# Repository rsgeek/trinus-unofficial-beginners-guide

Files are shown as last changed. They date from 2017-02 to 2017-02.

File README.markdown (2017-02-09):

# Trinus - The Unofficial Beginners Guide

This will enable Trinus owners that would like to contribute to the guide a better option via [Github Pull Requests](https://gist.github.com/Chaser324/ce0505fbed06b947d962).

You can also view the guide online using the Github Pages feature:

<https://drofnas.github.io/trinus-unofficial-beginners-guide/>

The latest compiled **PDF** document can be found in the [download](https://github.com/drofnas/trinus-unofficial-beginners-guide/tree/master/download) folder.

## Style Guide

This will go over the various styles/layout that are used throughout the Guide so that all contributions stay with the same format and it keeps a uniform look and feel.

### Text / Layout

For now, until this section of the style guide is flushed out, just copy the same style as the rest of the guide. It should cover the majority of things needed. Here's a [Markdown Cheatsheet](https://github.com/adam-p/markdown-here/wiki/Markdown-Cheatsheet) to help with any syntax not already used in the guide.

### Images

The original images (`orig` folder) are 3000px x 1500px (2:1) size. Then the images that are used in the document are just a reduction in size to 800px x 400px. If you want to have shorter height to your image, then you can create with a 4:1 ratio (3000px x 750px -> 800px x 200px).

Original Images (**PNG / JPG / PSD**):

* 3000px x 1500px (2:1)
* 3000px x 750px (4:1)

HTML / PDF Images (**PNG / JPG**):

* 800px x 400px (2:1)
* 800px x 200px (4:1)

#### Optimize Images

First thing you need to do is create the redued sized images (800 width) so that they can be optimized. All images should be uploaded to [TinyPNG.org](https://tinypng.com/) for processing. This process will reduce the file size of each image by as much as 70%. 

* Drag and drop images on to the website.
* Download the optimized version.
* Overwrite the images that you created for use for the HTML/PDF files (800w).

## Compiling

The HTML file is compiled using Pandoc (http://pandoc.org/index.html), see their website on how to install it on your machine. This will enable you to compile the latest development branch of this guide.

### Generate HTML
Make sure to get Pandoc (http://pandoc.org/index.html) installed first so that you can run the following command. The exact command may vary depending on your OS; this was what was run in OSX. See their website for OS specific changes to the command:

    pandoc *.md > docs/index.html --css helpers/style.css

### Generate PDF

* First generate the HTML using Pandoc above.
* Open the HTML file in Chrome.
* Click on File -> Print
* Change your Destination (or Printer) to "Save as PDF"
* Click the Save button to save it locally.

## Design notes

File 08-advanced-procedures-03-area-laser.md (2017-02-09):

### Maximize Build Area - Laser Engraving 
Paul Drinkut helped troubleshoot ([Facebook Post](https://www.facebook.com/groups/Trinus3D/permalink/1315472305181210/?hc_location=ufi)) the reason why the Laser Engraver wasn’t using the full build area, this was due to the fact the Laser Mount didn’t have the same left offset that the Extruder Assembly had. 

So in order to fix this, a modification was made to the official 3D Model (original model can be found in the [Downloads](#download-it) section) to add in a small left offset of 5mm. This combined with the X/Y-Axis offset screws allowed for the maximum engraving area to be achieved. 

If you haven’t already, you will need to follow the process to [Maximizing Build Volume in 3D Printing](#maximize-build-volume---3d-printing) first, then you can print the fixed Laser Mount (below) to maximize your laser engraving area.

**Modified Laser Mount** <br/>
[https://github.com/.../files/trinus-offset_laser_holder.stl 
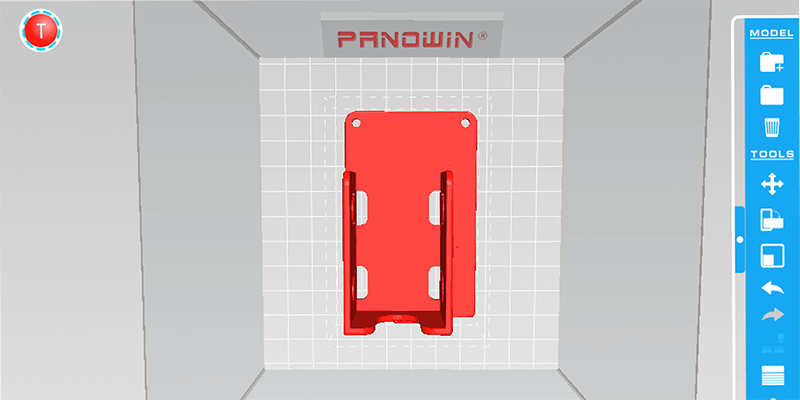
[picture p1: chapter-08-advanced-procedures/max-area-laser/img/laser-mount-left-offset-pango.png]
Pango - offset laser mount

](https://github.com/drofnas/trinus-unofficial-beginners-guide/blob/master/chapter-00-general/files/trinus-offset_laser_holder.stl)

> ##### Tip: Find center using a cross hair image
> Paul Drinkut had come up with a great idea of manually measuring out the center point of a piece of material (same size as the build plate), then use the laser to engrave a cross hair image to check if you have the laser centered. You can use a straightedge to extend the cross hair lines to the edge so that you can measure the results. ([Facebook Post](https://www.facebook.com/groups/Trinus3D/permalink/1318800631515044/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))
>
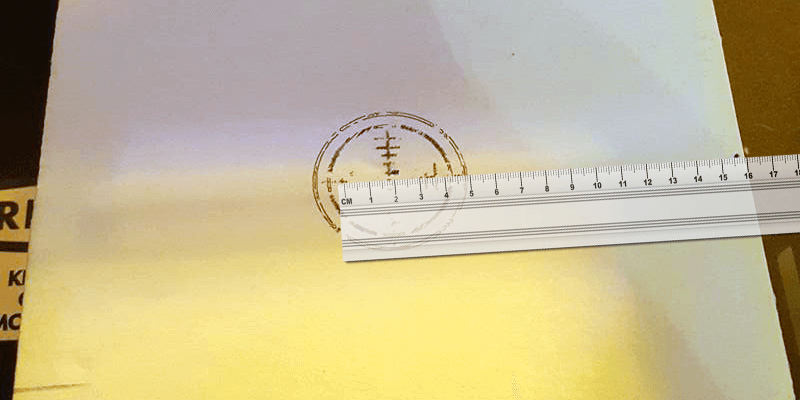
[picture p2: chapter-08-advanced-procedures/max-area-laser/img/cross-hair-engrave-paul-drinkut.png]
Cross hair engraving test
> 
> *Image by Paul Drinkut and Photoshopped Ruler added by John Sanford*

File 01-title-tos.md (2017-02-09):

# Trinus 3D Printer *The Unofficial Beginners Guide*

<div class="author">By: John Sanford and Claus Olesen</div>

<div class="toc">
* [Online Help](#online-help)
    * [Getting Started Videos](#getting-started-videos)
    * [Getting Started Guide](#getting-started-guide)
    * [Official Facebook Group](#official-facebook-group)
    * [Official Forums](#official-forums)
    * [Official Forums - Proven Solutions](#official-forums---proven-solutions)

* [Pre-Check](#pre-check)
    * [Heated Build Plate](#heated-build-plate)
    * [Normal Bed](#normal-bed)
    * [Spool Holder](#spool-holder)
    * [Pango](#pango)
        * [Download It](#download-it)
        * [Install It](#install-it)
        * [Setup USB Connection](#setup-usb-connection)
    * [Extra “Useful” Tools](#extra-useful-tools)
  
* [Set Nozzle Distance](#set-nozzle-distance)

* [First Print](#first-print)
    * [Loading Filament](#loading-filament)
    * [Download Pre-configured Test File](#download-pre-configured-test-file)
    * [Start Printing](#start-printing)
        * [Autoprint File on SD](#autoprint-file-on-sd)
        * [Using LCD](#using-lcd)
        * [Pango Console](#pango-console)
    * [Troubleshooting Print Issues](#troubleshooting-print-issues)

* [Printing Your Own Models](#printing-your-own-models)
    * [Fixing Your Models](#fixing-your-models)
    * [Common Pango Settings](#common-pango-settings)
        * [Settings](#settings)
        * [Expert Settings](#expert-settings)
    * [Start Printing](#start-printing)

* [Laser Engraving](#laser-engraving)
    * [Pre-Check](#pre-check-1)
    * [Installation](#installation)
        * [Disconnect Extruder Assembly](#disconnect-extruder-assembly)
        * [Attach the Laser](#attach-the-laser)
        * [Pango Setup](#pango-setup)
        * [Pango Laser Settings](#pango-laser-settings)
    * [How to Focus](#how-to-focus)

* [Advanced Procedures](#advanced-procedures)
    * [Update Firmware](#update-firmware)
        * [Check Firmware Version](#check-firmware-version)
        * [Update Firmware](#update-firmware)
    * [Maximize Build Volume - 3D Printing](#maximize-build-volume---3d-printing)
        * [Helpful Print](#helpful-print)
        * [Adjust the Offset Screws](#adjust-the-offset-screws)
    * [Maximize Build Area - Laser Engraving](#maximize-build-area---laser-engraving)
    * [Print Over Wifi - OctoPrint](#print-over-wifi---octoprint)
        * [More Questions?](#more-questions)
    * [Third Party Slicers](#third-party-slicers)
        * [Simplify 3D (S3D)](#simplify-3d-s3d)
        * [Cura](#cura)
        * [Other Slicers](#other-slicers)
* [Maintenance](#maintenance)
    * [Axis Sliders](#axis-sliders)
    * [Nozzle Cleaning - Cold Pulling](#nozzle-cleaning---cold-pulling)
* [Revision History](#revision-history)
</div>

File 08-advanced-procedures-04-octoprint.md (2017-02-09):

### Print Over Wifi - OctoPrint
Here’s a quick guide to get OctoPrint up and running, which was very straight forward. I used a Raspberry Pi 3 and OctoPi to get OctoPrint up and running quickly. 

* Installed the latest version of OctoPi on the Raspberry Pi 3’s SD Card. See [OctoPi’s website](https://octopi.octoprint.org/) on how to do this process for your setup.
* Followed these instructions to get the WiFi setup properly with the RPi 3: <https://www.youtube.com/watch?v=dZeJb6Jv-9E>
* After the network stuff is sorted, you can open your browser to the IP Address (*http://192.168.X.XXX*) of the RPi.
* Now you can go through initial install steps of setting up a username/password, after which it will ask you to update to the latest version of OctoPrint (if not already the latest).
* After the update process is complete, it will reload the OctoPrint service.
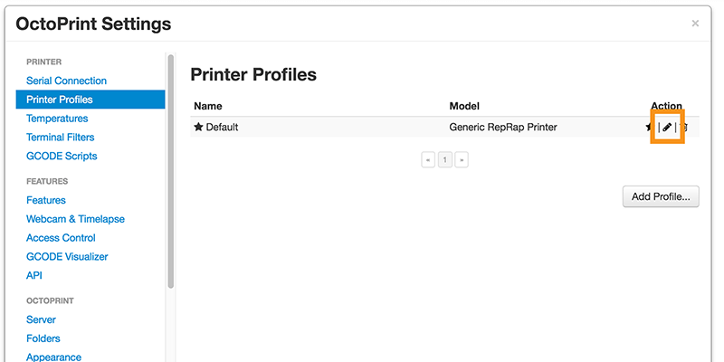
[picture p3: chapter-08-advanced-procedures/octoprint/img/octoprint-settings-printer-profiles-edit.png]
OctoPrint - printer profile edit
* Time to update the Default Printer Profile, just so that OctoPrint knows a little about your printer. Go into Settings -> Printer Profile, then Edit the Default. 
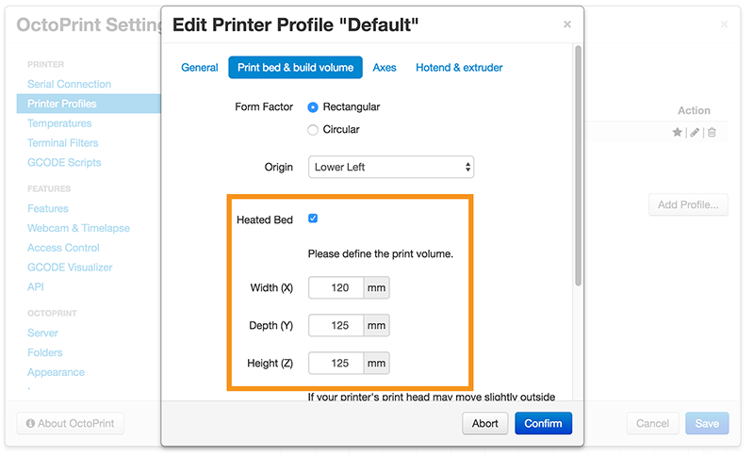
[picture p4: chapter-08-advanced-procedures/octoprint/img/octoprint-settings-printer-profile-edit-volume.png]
OctoPrint - printer profile volume
* Now update the Build Volume and tell OctoPrint if you have a Heated Bed installed. 
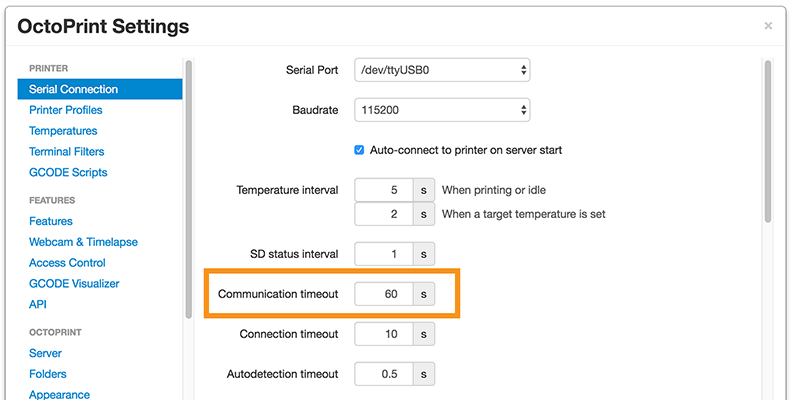
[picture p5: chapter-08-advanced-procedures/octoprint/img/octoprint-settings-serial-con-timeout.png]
OctoPrint - serial timeout
* It’s also a good idea to change the Communication Timeout to around 60 seconds; sometimes the Trinus can be slow to respond to messages during the heat up phase. So this is to ensure the model continues printing even if the communication takes a little longer than normal. 
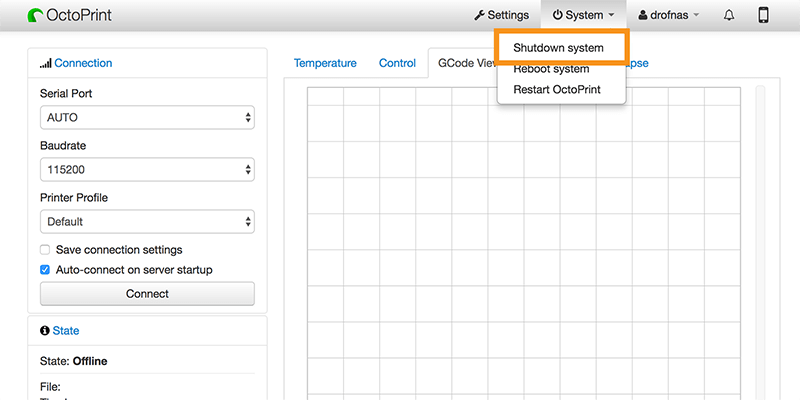
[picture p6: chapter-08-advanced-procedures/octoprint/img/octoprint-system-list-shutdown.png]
OctoPrint - system shutdown
* If the device isn’t currently sitting next to your Trinus, you will need to shut it down so that you can move it to it’s final resting place. 
* Plug the device in next to your Trinus, get both devices powered up, then connect the USB cord from the Trinus to the RPi.
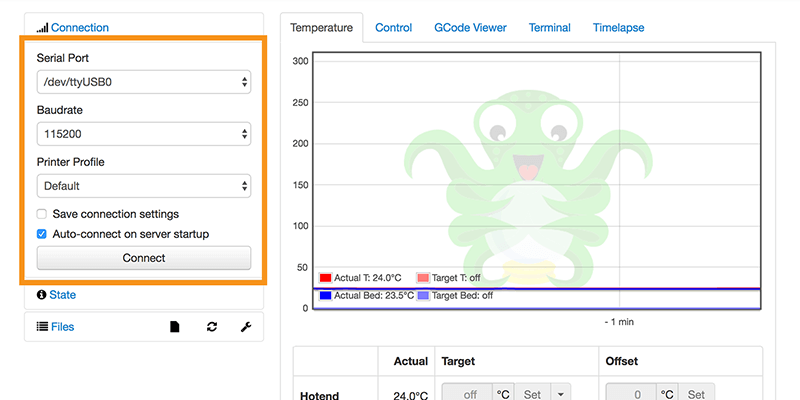
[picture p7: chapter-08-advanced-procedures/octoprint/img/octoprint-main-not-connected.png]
OctoPrint - not connected
* Open the browser on your computer and browse to the IP Address of your RPi (*http://192.168.X.XXX*), after you login, using the credentials you created earlier, you can now connect to the printer. 
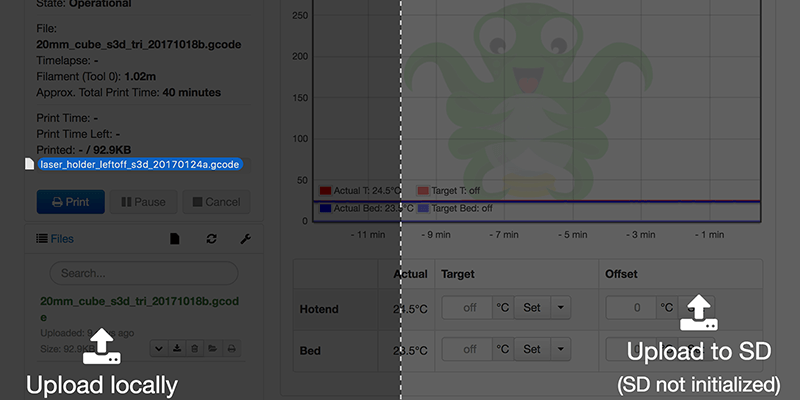
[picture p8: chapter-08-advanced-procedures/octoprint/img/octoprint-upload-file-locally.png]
OctoPrint - upload locally
* Now you can Drag and Drop your files to the local file system. Since currently it’s not possible to upload to the SD card stored on the Trinus. 
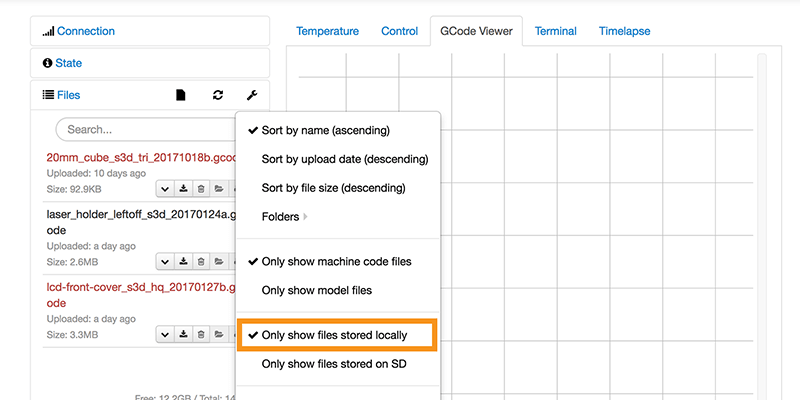
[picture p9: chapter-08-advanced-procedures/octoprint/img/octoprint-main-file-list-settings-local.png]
OctoPrint - view local contents
* If you don’t see your newly uploaded files, you may need to change the setting to see files stored locally. 
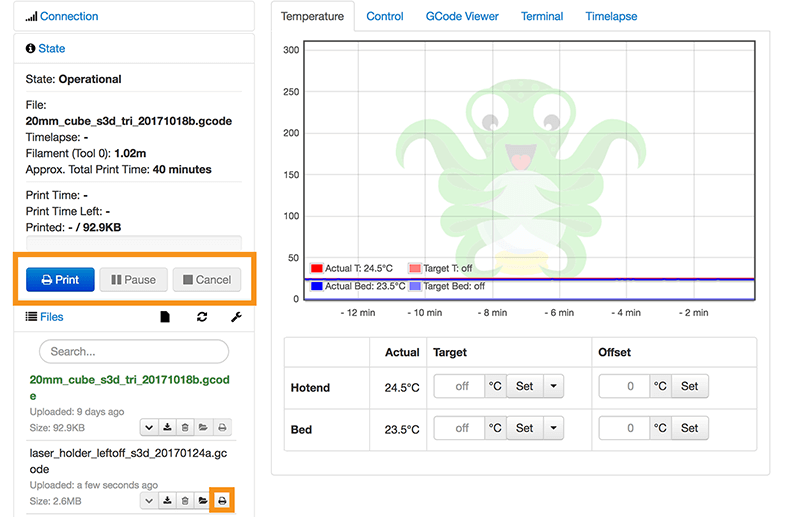
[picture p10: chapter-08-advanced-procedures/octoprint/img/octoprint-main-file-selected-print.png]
OctoPrint - print selected file
* Then simply click the Print button for the file you want to print and it will stream it to the Trinus with no issues. Or if you click a File Name, you can then click on the Blue Print button above the file list. The small print button is greyed out for the selected (green name), so you need to use the larger one above. 

#### More Questions?
If you find you still have questions regarding the finer details for setting this up, please check out [Thomas Sanladerer’s](https://www.youtube.com/channel/UCb8Rde3uRL1ohROUVg46h1A) video on the subject. 

**Getting started with OctoPrint on the Raspberry Pi 1, 2 and 3! [2016 edition]**
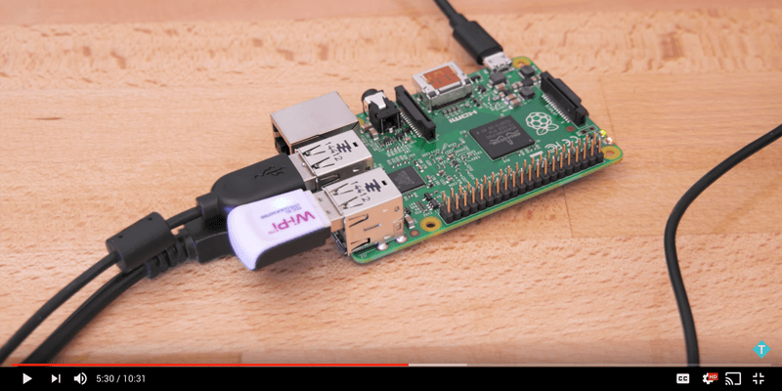
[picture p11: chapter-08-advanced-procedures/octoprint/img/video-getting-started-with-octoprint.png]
OctoPrint - getting started video
[https://www.youtube.com/watch?v=MwsxO3ksxm4 ](https://www.youtube.com/watch?v=MwsxO3ksxm4)

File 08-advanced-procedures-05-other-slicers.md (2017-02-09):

### Third Party Slicers
A slicer is what you use to turn a 3D model ([STL](https://en.wikipedia.org/wiki/STL_%28file_format%29) file) into a Gcode file, this is what defines how the 3D Printer moves, amount of material to push out, speed, temperature, etc. If you're curious what all those Gcode values do, there’s an [online wiki](https://en.wikipedia.org/wiki/G-code) that describes them all.

For the Settings, please read the provided Forum Threads as they have helpful tips and solutions that people have come up with for that respective slicer. Plus those threads are also a great place to ask questions and share your own modifications.

#### Simplify 3D (S3D)
<https://www.simplify3d.com/> <br/>
Considered to be the best of the best when it comes to slicers. But it also comes with a steep price tag of **$150**. So if you are planning on making money from 3D Printing, it might be worth the investment.

**Forum Thread:** <br/>
<http://www.kodamaforums.com/phpBB3/viewtopic.php?f=20&t=5>

> ##### Tip: Configuration Assistant
> In the Help menu is a Configuration Assistant that will allow you get the most recent profile for the Trinus 3D Printer, it’s currently listed as “Kodama Trinus”. Currently (as of the writing of this guide) there is a bug in this profile that prevents you from printing via SD Card. A user in the forums had posted a very simple fix for this:
> <http://www.kodamaforums.com/phpBB3/viewtopic.php?p=1741#p1741>

#### Cura
<https://ultimaker.com/en/products/cura-software> <br/>
This is an excellent free option with a ton of features, and is a great starting point if you want to venture out into the world of 3rd Party Slicers.

**Forum Thread:** <br/>
<http://www.kodamaforums.com/phpBB3/viewtopic.php?f=20&t=1423>

> ##### NOTE
> Currently it doesn’t seem possible to use Cura to connect to your printer over USB in Windows / Mac; users have had success with Linux though. So if you need a way to print via USB then I’d suggest one of the Other Slicers such as Repetier (<https://www.repetier.com/>) or even [OctoPrint](#print-over-wifi---octoprint) for printing over WiFi.

#### Other Slicers
Here’s a quick list of other slicers, but I haven’t seen anyone mention settings to be used with them. Will update this document with Forum links if I come across them, or someone recommends them. You can try using the same settings from Cura / S3D as a starting point for these as well.

**Slic3r** - <http://slic3r.org/> <br/>
**Repetier** - <https://www.repetier.com/> <br/>
**CraftWare** - <https://craftunique.com/craftware> <br/>

There are plenty of [other options for slicing](https://all3dp.com/best-3d-slicer-software-3d-printer/), but these are the most popular ones that I’m aware of. If you feel another should be added to the list, and you have some settings for it, please add a comment in the [forums](http://www.kodamaforums.com/phpBB3/viewtopic.php?f=21&t=1627).

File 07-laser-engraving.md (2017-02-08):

## Laser Engraving

### Pre-Check
**Safety First:** <br/>
Your Laser Engraver should have come with some Green Safety Glasses, please wear these the ENTIRE time you are around the laser while it’s on. The last thing you want to do is lose an eye because you thought, “It’ll never happen to me.”

##### JUST WEAR THEM ALREADY...no seriously, I’ll wait. {.warning}

**Official Video: Laser Installation and Usage** <br/>
Here’s a little video on how to install the laser assembly and the basics of getting it set up. <br/>
<https://vimeo.com/album/4289066/video/196594883>

**Check Firmware** <br/>
There was an update to the firmware that fixes an issue with the laser staying on after click on the stop / pause button. So you will want to ensure you have the latest firmware (v3.5.6+)  installed before using the Laser Engraver (see [Update Firmware](#update-firmware) section).

**Do you have all the parts?** <br/>
Just a quick confirmation that you have the 3 items needed to start your laser engraving adventure; Laser, Laser Mount, and Safety Glasses. If for some reason you didn’t get a Mount, you can print a copy of it, the file is available in the [Downloads](#download-it) section, OR you can print the **fixed** one referenced in the [Maximize Laser Build Area](#maximize-build-area---laser-engraving) section.
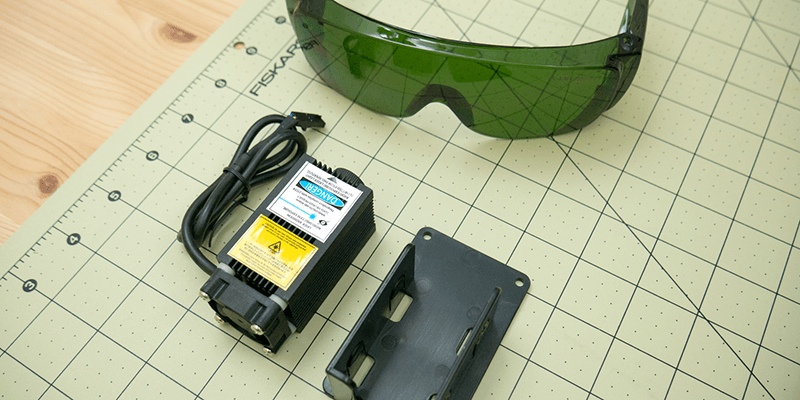
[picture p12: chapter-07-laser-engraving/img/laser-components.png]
Laser components


### Installation
#### Disconnect Extruder Assembly
* Let’s start by loading up the Pango Console (see [USB Connection](#setup-usb-connection) section).
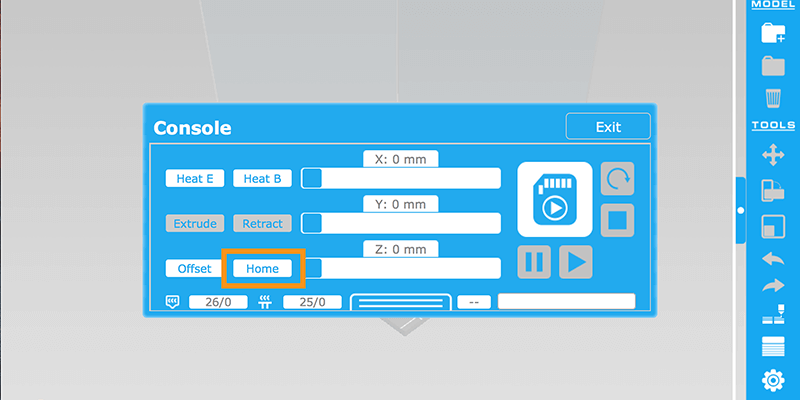
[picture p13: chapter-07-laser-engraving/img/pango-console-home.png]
Pango - console home
* Home the extruder head so the printer knows where all the axes currently are. 
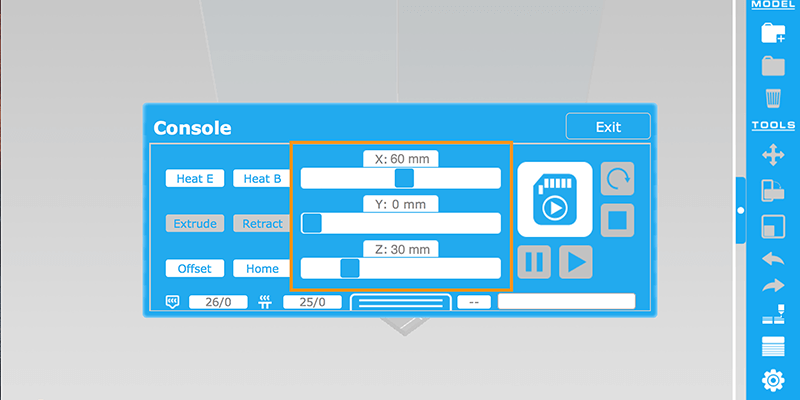
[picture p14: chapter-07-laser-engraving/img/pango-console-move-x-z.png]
Pango - console move x-y
* Now move the Z axis up to about 30mm, then the X to around 60mm. 
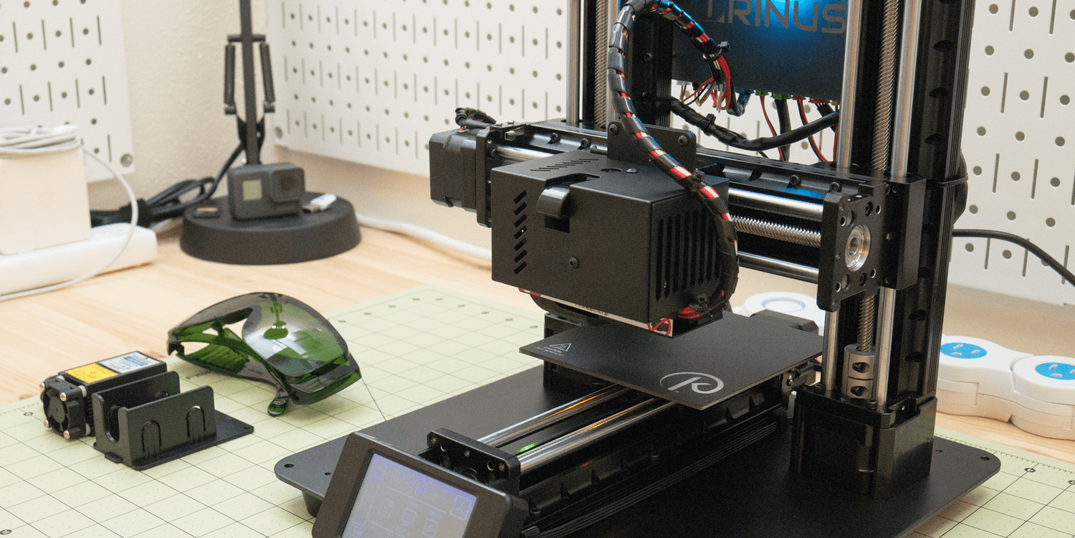
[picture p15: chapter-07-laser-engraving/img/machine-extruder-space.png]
Move extruder
* This is to give us a little bit of room while we remove the extruder. 
* **Unplug the Power**
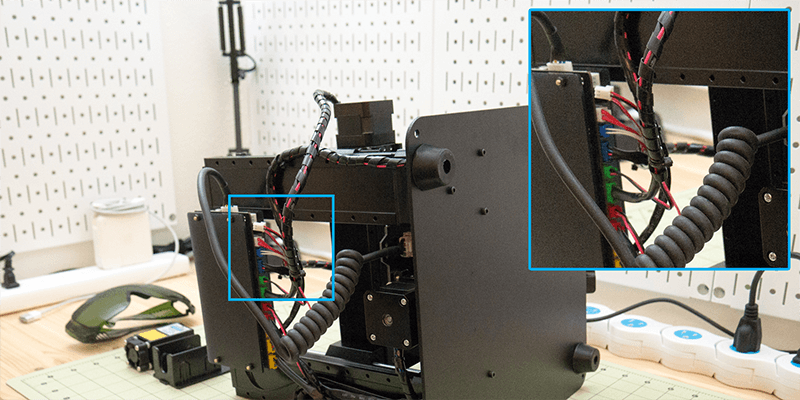
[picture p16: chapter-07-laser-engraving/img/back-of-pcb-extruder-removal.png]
PCB extruder connections
* Now we can turn the machine around (remove enclosure if you have this installed) and disconnect all the wires for the Extruder Assembly. You should see 2x Blue, 2x White, and a Black connector. Please pull them out by the connector (plastic part) and not the wires, as this can cause them to break or come loose. 
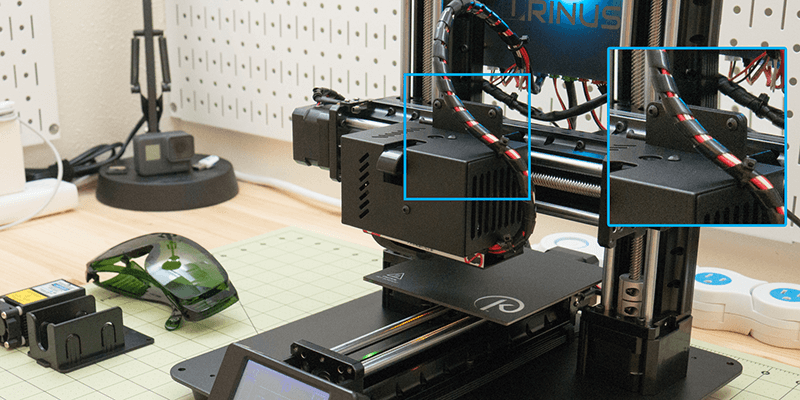
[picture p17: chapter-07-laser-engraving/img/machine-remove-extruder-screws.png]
Remove extruder screws
* Now it’s time to unscrew the top 2 screws holding the Extruder Assembly to the X-axis. 
* Set the Extruder Assembly aside while we install the laser.

> ##### Tip: Why Disconnect the Extruder?
> While testing the Laser Engraver a community member had left the extruder connected and he quickly discovered that there is a bug in the current firmware that turns on the Heater for the Extruder while engraving. 
> 
> This may be fixed in the future, but I would consider it a “**Best Practice**” to completely remove the attachments that you aren’t currently using.

#### Attach the Laser
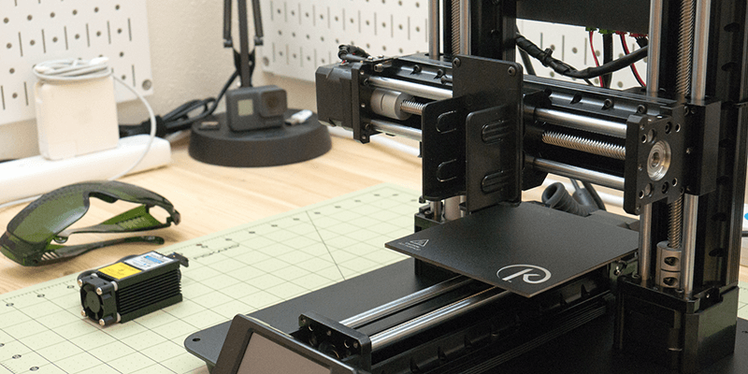
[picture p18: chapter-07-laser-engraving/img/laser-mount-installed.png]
Laser mount
* Start by attaching the mount for the laser using the 2 screws you removed when disconnecting the Extruder Assembly. 
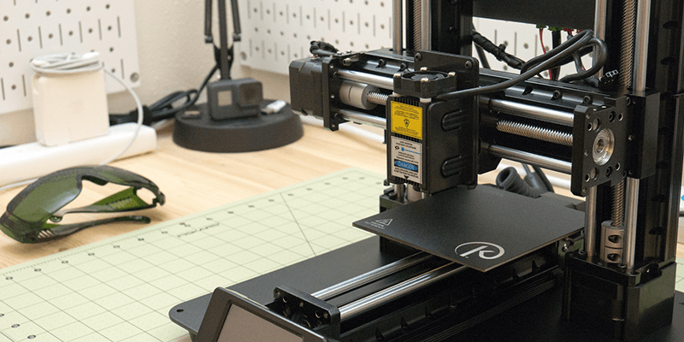
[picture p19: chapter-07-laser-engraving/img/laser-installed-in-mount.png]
Laster mounted
* Now clip the Laser Engraver into the mount. 
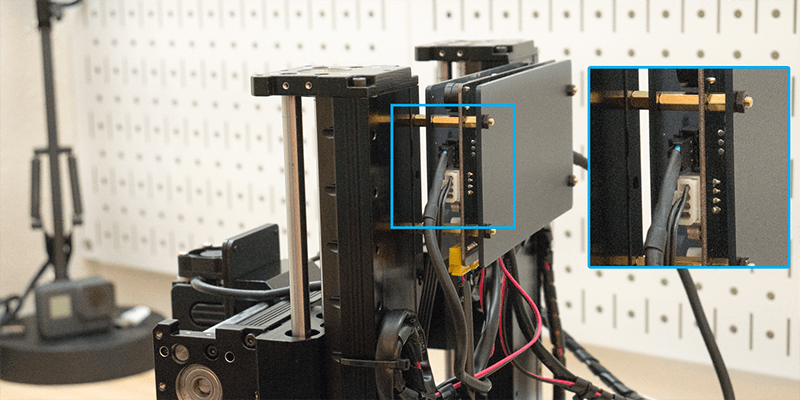
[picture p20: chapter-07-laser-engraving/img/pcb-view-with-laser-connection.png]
Connect laser to PCB
* Connect to the cable to the PCB, small black connector right above the white LCD connection. 
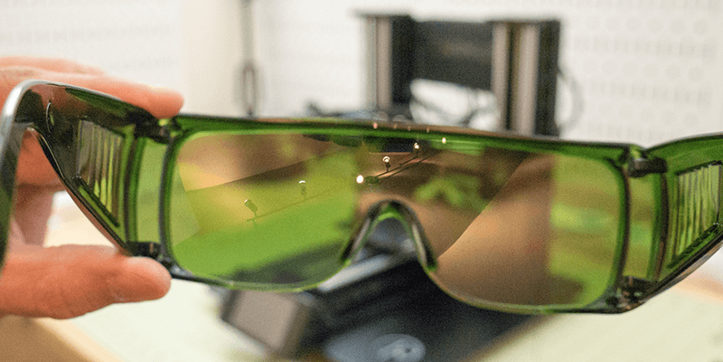
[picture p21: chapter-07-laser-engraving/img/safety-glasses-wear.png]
IMG ALT
* All installed. Time for those Safety Glasses. 

#### Pango Setup
In order to start using Pango to slice your images for engraving, you will first need to tell Pango that you’ve installed this tool head.

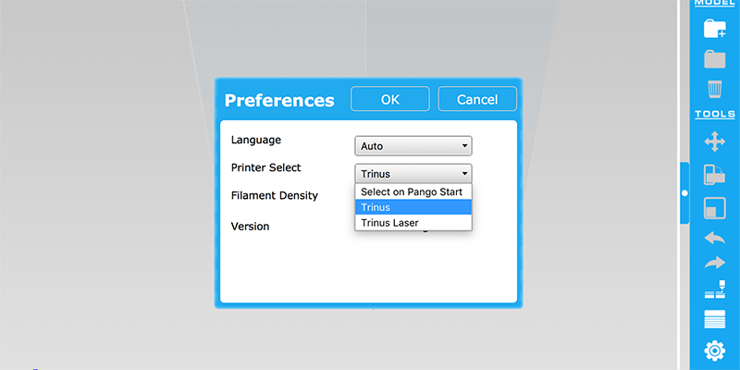
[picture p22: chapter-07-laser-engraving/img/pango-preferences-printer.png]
Pango - change printer type
* Go into Preference -> Preferences (Windows) or Pango -> Preferences (Mac) and change the “Printer Select” to “Trinus Laser” 
* Pango will now tell you it needs to restart, click Ok and let it restart. If you’re on a Mac, Pango doesn’t automatically re-open so you will need to open it back up and it should be in Laser Engraving Mode.
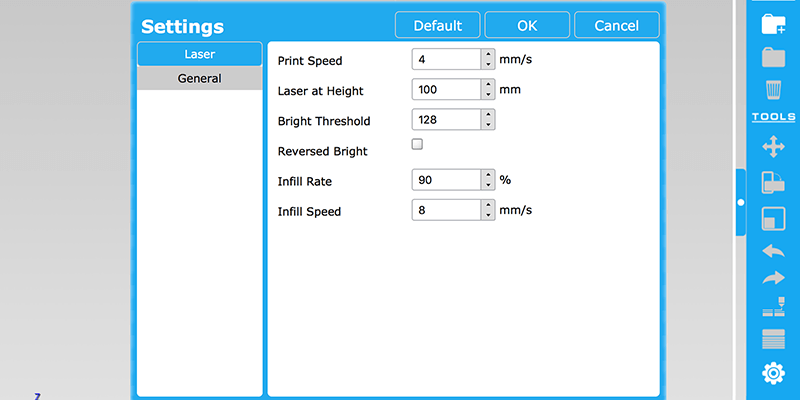
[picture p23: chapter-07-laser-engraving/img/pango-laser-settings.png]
Pango - laser settings
* You will see a whole new set of Settings available for the engraving process (discussed below). 

#### Pango Laser Settings
* **Print Speed** <br/> 
This is the speed at which the laser is moving while on/engraving. If you are working with Dense material (ie, Maple Wood), you’ll want to slow this down, and of course you have the option to speed up for Soft materials (ie, Balsa Wood). You can also speed this value up if you want the engraved area to be a bit lighter (less burned) as it will have less time to do it’s magic.
* **Laser At Height** <br/> 
The laser can focus anywhere from 80-100mm away from the material you plan on engraving. So you will need to adjust this value to the height of the material (in millimeters) you are using + the focusing distances of 80-100mm.
* **Bright Threshold** <br/> 
This value will let you determine if an area of your picture is considered a Dark area or a Light area, since Pango currently doesn’t support Grayscale, you get to determine if the pixel will show up in the final product. You can see this in action in the official video provided above at around the [4min mark](https://vimeo.com/196594883#t=240s).
* **Reversed Bright** <br/> 
Toggle to choose if you want the Light or Dark areas of your image engraved. By default this is unchecked and the Light colors areas will be burned into the material.
* **Infill Rate** <br/> 
For large areas that need to be engraved, you can choose how much of this area you actually want burned into the material. For example if you choose 50%, then only half of the infill area will be burned onto the material.
* **Infill Speed** <br/> 
This is exactly like the Print Speed but it applies to the Infill. If you want the infill to be a lighter color than the outline (which is what the Print Speed is for), then you can simply increase the speed of this value, Or set it the same as the Print Speed if you want them both to be a uniform shade.

### How to Focus
For focusing your laser, you should watch how this is done in the official video.

> ##### WARNING {.warning}
> Some materials will give off toxic fumes, as one user discovered when engraving Chromed Leather. So if you plan on venturing out beyond your standard Wood blocks, I’d suggest doing some google searches on that specific material to ensure it’s safe to burn.

**Trinus - Laser Installation and Usage** <br/>
[https://vimeo.com/196594883#t=389s
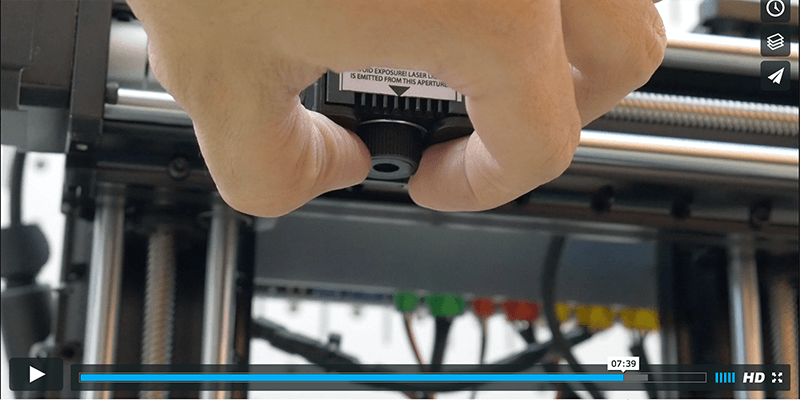
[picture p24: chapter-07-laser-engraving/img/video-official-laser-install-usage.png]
Laser install and usage video

](https://vimeo.com/196594883#t=389s)

Now that you are all focused up, time to start finding things around the house to engrave (see <span class="warning">**WARNING**</span> above about choosing materials).

> ##### Tip: 10 Tips and Tricks
> Stumbled across this Instructable on various tips and tricks when working with laser engravers. Some good information if you are completely new to laser engraving. 
<http://www.instructables.com/id/10-Tips-and-Tricks-for-Laser-Engraving-and-Cutting/>

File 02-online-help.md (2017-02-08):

## Online Help

There are plenty of active users in the Trinus community right now, so don’t be afraid to ask as many questions as possible. This document will try and get you started, but there’s always unknowns that will crop up and the following options will help you get through those.

### Getting Started Videos

I highly suggest you watch all these videos just to get your bearings before you start your build process.

#### Official Videos
Getting Started: <https://vimeo.com/album/4289066> <br/>
Printer Assembly: <https://vimeo.com/164016762>

#### Trinus Tips and Breakdown Videos
Terrible quality and terribly useful <br/>
<https://www.youtube.com/channel/UCMnqd6BRofGVrfA0u4806YQ>

> ##### NOTE
> The Printer Assembly video was created using a **Prototype** unit during the Kickstarter Campaign; before the production units were realized, so there will be some differences. Even with that said, I still feel it’s a great video to watch before assembling your printer (No Assembly Instructions? Check the [Downloads](#download-it) section).

<!-- -->

> ##### WARNING {.warning}
> Make sure when attaching the Extruder Assembly / Laser Mount, that you **don't over tighten the screws**. This can mess with the threading of the mount point but also cause your screws to get stuck to the point of having to using a Drill / Dremel to cut the screw head for removal. To help with this process, hold the included wrench so that you are holding the shorter section, to reduce the amount of torque you can apply.

### Getting Started Guide
Some good general information, plus some great ideas in the comments. <br/>
<http://www.kodamaforums.com/phpBB3/viewtopic.php?f=21&t=7>

### Official Facebook Group
<https://www.facebook.com/groups/Trinus3D>

### Official Forums
<http://www.kodamaforums.com/>

### Official Forums - Proven Solutions
Here’s a forum section dedicated to helping people with solutions that work. Great place to start when you run into issues. <br/>
<http://www.kodamaforums.com/phpBB3/viewforum.php?f=22>

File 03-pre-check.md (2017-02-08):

## Pre-Check

### Heated Build Plate

Please ensure you installed the small black spacer under the bed first. See how it’s installed in the official video:

[https://vimeo.com/album/4289066/video/195241496
Heated bed spacer
](https://vimeo.com/album/4289066/video/195241496) 

You will also **need** to install the BuildTak material on top of the Heated Bed. You can’t print directly on the surface of this bed, since it’s too slick anything to stick. Plus there is a good chance of ruining your brand new heated bed if you tried.

> ##### Tip: Installation Tweak ([Forum Thread](http://www.kodamaforums.com/phpBB3/viewtopic.php?f=22&t=1467))
> You want to make sure you install a zip tie around the cable connection and through the holes at the back left of the heated build plate. This is to help reduce any fatigue caused by the constant motion.
> 
>  <div>
>  Heated bed zip tie support
>  *Idea provided by Roi Igarashi @ Kodama*
>  </div>
> 
> ##### WARNING {.warning}
> The downside to having a secured cable (above image), is that the zip ties rounded bump will crash into the small fan shroud at the bottom of the Extruder Assembly. So you will need to stay away from this little corner when slicing models. If you come up with a better working solution to keep the cable secure, please leave feedback on Facebook or the Forums.

<!-- -->

> ##### Tip: Secure cable to the Z-Axis
> it’s also a good idea to secure the end of the pigtail loop to the Z-axis slider.
> 
> <div>
> Heated bed cable tied to Z-axis
> *Idea and image provided by Rick Miller*
> </div>

<!-- -->

> ##### Tip: Part Removal
> One of the community members (sorry, can’t remember who told me about it) had posted about how they like to heat up the build plate to about 60C to help with the removal of the printed models. 
>
> Using one of the recommend [removal tools](#extra-useful-tools) you should slowly work your way under an edge of the printed object, then move the tool around the entire underside of the model until it’s fully released. This will help ensure your BuildTak material lasts a good long time. 
>
> ##### WARNING {.warning}
> Please **DO NOT** try and rip the model from the BuildTak, this is how you destroy the surface and it ends up being very expensive to keep replacing them. This also ensures you don’t prematurely destroy your heated bed in the process.

<!-- -->

> ##### Tip: Cleaning
> Heat build plate to 100C to soften any residue that might have been left behind after removing your printed models, so it will be easy to clean up with your [removal tool](#extra-useful-tools) of choice. 
>
> Here’s a video showing how to clean the BuildTak material with 70% Alcohol as well: <https://www.youtube.com/watch?v=BrJc2cqYeXI>

### Normal Bed
This is installed on its own, **don’t use** the small black spacer from the [Heated Bed](#heated-build-plate).

### Spool Holder
OMG where is my Spool Holder? Well, this is meant to be one of your first functional prints. You have the option to grab the official spool holders or one of the community created options. While printing these, you can simply stand your spool up behind the printer, then check on it during printing to ensure it doesn’t get tangled up on anything.

**Official Spool Holders (see [Downloads](#download-it) section)**
Official spool holders
*Normal Spool Holder (left) and Enclosure Spool Holder (right)*

**Community Created Spool Holders** <br/>
[http://www.thingiverse.com/search?q=trinus+spool+holder 
Thingiverse spool holders
](http://www.thingiverse.com/search?q=trinus+spool+holder)

### Pango
Get the latest version (2.3+) as it will be needed to get you set up.

#### Download It
**Facebook Group - Files Section** <br/>
<https://www.facebook.com/groups/Trinus3D/files/>

**Forum Post - Facebook File Sync** <br/>
Since as of this writing the [Forum Downloads](http://www.kodamaforums.com/phpBB3/page/downloads) section doesn’t have the same files as the Facebook Group (this may change when things settle down on Kodama’s side), but for now these files have been downloaded and tossed into a DropBox share; latest additions will be posted here: <br/>
<http://www.kodamaforums.com/phpBB3/viewtopic.php?f=21&t=363>

#### Install It
**Windows** <br/>
You can run Pango from any directory. Just open the “pango.exe” file.

**Mac** <br/>
Move Pango application from your Downloads folder to your Application folder. This is due to the security restrictions that OSX applies to the Downloads folder.

#### Setup USB Connection
It’s very important to get your USB connection setup now, else you may go mad trying to get your printer running at peak performance.

**Mac USB Connection** <br/>
<http://www.kodamaforums.com/phpBB3/viewtopic.php?f=8&t=370>

**Windows USB Connection** <br/>
<http://www.kodamaforums.com/phpBB3/viewtopic.php?f=22&t=304>

**Test USB Connection** <br/>
If for some reason you can’t complete these steps, please post details about your system in the forum threads above, so that the community members can help you out.

* Connect the Power and USB Cables to your Trinus.
* Once fully powered up, connect the USB Cable to your computer.
* Open Pango, and click on View -> Console Pango - view console
* Select the USB connection from the Port list. Pango - connect to Ccnsole
* Now click on the Console button in this window, to view the Printer Controls. Pango - console
* Now click on the “Heat E” button to heat up the Extruder. The LED on the Trinus should change to Red if all goes well. Click the “Heat E” button again to stop the process. Pango - console highlight heat-e button
* USB Test Successful.

> ##### Tip: Mac just won’t connect for me (advanced option)
> If you happen to have a copy of Windows 7+ lying around, then you can install a copy of windows into a “virtual machine” using free software like VirtualBox (<https://www.virtualbox.org>).

### Extra “Useful” Tools
The Trinus contains with the basics when it comes to tools you may need. But here are a few other items that will make your life easier when starting out.

#### Pliers
If you EVER plan on changing your Nozzle (getting different sizes or extra 0.4 nozzles) you will want these to hold the nozzle when it’s hot. Plus these are great for grabbing the support material / rafts and ripping them away from your model.

#### Wire Cutters
I find these are great to have around for cutting a 45deg angle in the filament before trying to load some up, cutting bad sections of filament off, and even making a clean cut at the end of zip ties

**Recommendation** <br/>
Flush Cutters - [US](http://amzn.to/2jVOVSx) / [UK](https://www.amazon.co.uk/dp/B0052RPBY6) (love these things)

#### Hobby Spatula / Paint Scraper
This will help a TON when trying to remove the prints from the build plate. Things have a tendency to stick pretty darn good to the BuildTak material provided. You can even get some thin metal Paint Scrapers from your local hardware store.

**Recommendations** <br/>
Hobby Spatulas - [US](http://amzn.to/2kmnePr) / [UK](https://www.amazon.co.uk/dp/B006YR55ZS/) <br/>
Japanese Spatula - [US](http://amzn.to/2jkeoEk) / [UK](https://www.amazon.co.uk/dp/B001ILG3SI/)

#### Precision Screwdriver Set
This will come in handy whenever you need to break down your Extruder Assembly. Due to the fact the assembly contains 1.5mm grub screws. 

**Recommendation** <br/>
45 Piece Screwdriver Set - [US](http://amzn.to/2kEQphG) / [UK](https://www.amazon.co.uk/dp/B01KTSU340)

#### SD Card Reader
If your computer doesn’t already have one, get one, all you’ll do is drive yourself CRAZY if you don’t have one of these. 90% of all 3D printers use SD Cards, so if you ever plan on expanding your printer collection, get one… just GET ONE.

> ##### Tip: You might have one
> Most Laptops have these built-in as well, so please check if you already have one.

#### M3/M4 Screws/Nuts
Get a variety pack of these screws and nuts, especially if you’re in the US, since it can be a PAIN to find the right length that you need. Also get some **M3 x 25mm and M3 x 30mm** screws, the 25mm length ones are what’s currently used for the Axis Offset Screws, but if you wanna play around with using a Glass Bed, you will need longer screws (hence the 30mm ones).

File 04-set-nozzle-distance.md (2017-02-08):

## Set Nozzle Distance

Now that we have all the **Pre-Check** steps complete, we can start the process of getting your nozzle set up so that you have a successful first print.

> ##### WARNING {.warning}
> Please make sure the nozzle is cool (Cyan LED on Control Board) before performing this process. That way you don’t accidentally melt your non-heated bed (image below), the BuildTak material, or damage your Heated Bed.
> 
> <div>
> Damaged normal bed from hot nozzle
> *Image provided by Claus Olesen*
> </div>

* Connect to your Printer via Pango, and go to the Console (See [USB Connection](#setup-usb-connection) section).
* Click on the Home button to move the extruder assembly into place. The tip of the nozzle may align a few millimeters in front of the build plate, we’ll save that for later, let’s get printing first. Pango - console home button
* You want the Nozzle about 2 pieces of paper away from the build plate (0.2mm). Nozzle distance
* If the distance isn’t quite right, we will need to set the Offset value for the “Z” axis within Pango. Click on the “Offset” button in the Pango Console window. Positive Numbers moves the nozzle closer to the bed, Negative Numbers moves it away. This can have a **max value of -1.5mm to 1.5mm**. If you can’t get it adjusted perfecting with that in mind, see the [Adjusting Offset Screws](#adjust-the-offset-screws) section. Pango - console z-offset
* Set the value in small increments (0.01mm), then click the Home button again, repeat until your pieces of paper can slide under the nozzle but have a little bit of tension. Nozzle distance paper check
* All done, let’s get printing.

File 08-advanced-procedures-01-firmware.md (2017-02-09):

### Update Firmware
If you want to ensure your Trinus is up to date with the latest firmware, which may fix known issues, then here’s a quick look on how to do this process. You can get the latest version of the firmware from the [Downloads](#download-it) section.

#### Check Firmware Version
* Connect your Trinus to your PC/Mac via USB.
* Load up Pango and open to the Pango Console, then click on the tab at the bottom. Pango - terminal button
* Near the top of the Terminal window you will see the version of Firmware you have installed. Seen here we have version “3.5.6-03” installed. Pango - view terminal

#### Update Firmware
* Go back into the Console connection screen, and click on the Firmware button. Pango - console firmware button
* Now browse to the “.hex” file that you downloaded prior, then open it up. The update process will start. Pango - select firmware file Pango - firmware updating
* It can take a up to few minutes, but it will eventually finish with the following message. Pango - firmware updated

> ##### NOTE
> If for some reason it fails the first time, try again. If you can’t get it updated you may need to email [support@kodama3d.com](mailto:support@kodama3d.com) to help you track down the root cause of your issue.

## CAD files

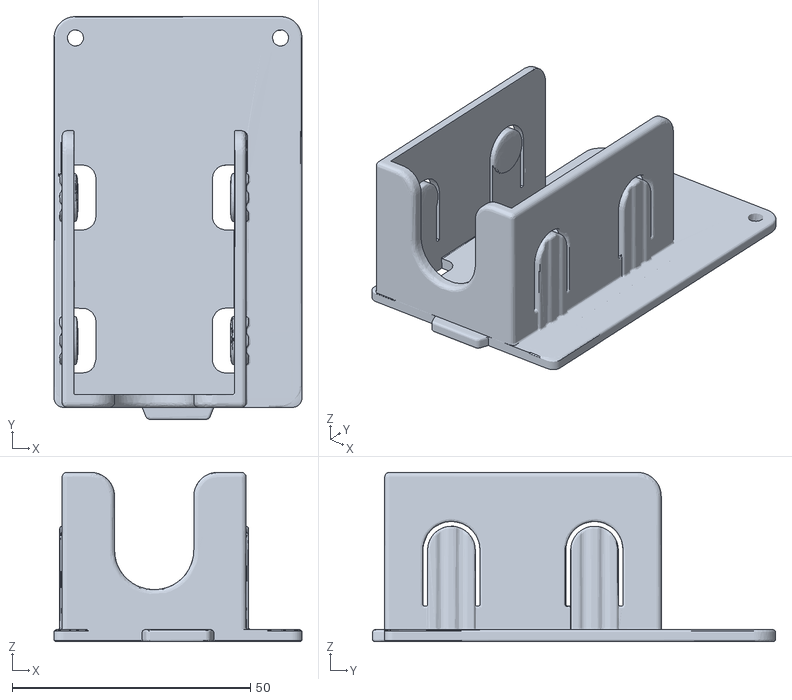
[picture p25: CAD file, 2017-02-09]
docs/chapter-00-general/files/trinus-offset_laser_holder.stl
52.0 x 84.5 x 35.5

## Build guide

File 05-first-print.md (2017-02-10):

## First Print

Some of the SD Cards that came with the Trinus were blank. But you can get all the files that were meant to be included on the card online, see the [Download](#download-it) section above, as these files are stored alongside Pango.

Before loading up your SD card with any files, it’s recommended to reformat it using FAT32 file system. Users have experienced random stops when using bad SD cards, which seem to be corrupting the files stored on them; formatting the card can help prevent this. If you’re not sure how to format an SD card, google is your friend: [Windows](https://www.google.com/webhp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) | [Mac](https://www.google.com/webhp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)

> ##### Tip: What do all those beeps and LED colors mean?
> Here’s a forum post describing what the various colors and sounds mean:
<http://www.kodamaforums.com/phpBB3/viewtopic.php?f=22&t=1440>

<!-- -->

> ##### Tip: Formatting didn’t help
> You might have a bad SD Card. If you have another SD Card available that is 32GB or smaller, try that one and see if that fixes your printing problem.

### Loading Filament
I think for this one, it’s better explained in a video format. So here’s a detailed video on loading filament into the Trinus. A [quick tip version](https://youtu.be/7yxVfIXOCTI) is also available on the same YouTube channel, if you just want the 1min quick and dirty walkthrough.

**Breakdown: Trinus - Loading Filament** <br/>
[https://youtu.be/oYl3rGYUAbo
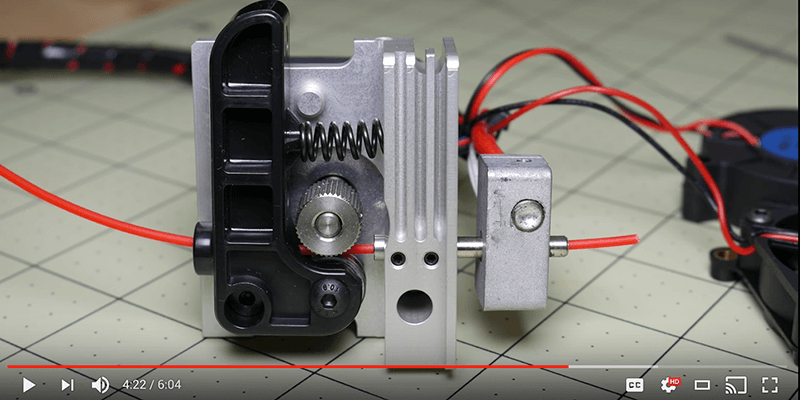
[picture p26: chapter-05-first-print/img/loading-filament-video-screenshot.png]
Loading filament breakdown video

](https://youtu.be/oYl3rGYUAbo)

> ##### Tip: Filament Guide (advanced upgrade, not required)
> Here’s a filament guide widget that will help you with loading filament, of course you need to at least load it once without this guide, so that you can print the model. The creator of this model recommends using PETG filament; so your mileage may vary using less heat resistive materials such as PLA. If you're completely new to 3D Printing this might be a daunting mod, since you need to dismantle your Extruder Assembly in order to install this.
<http://www.thingiverse.com/thing:2041586>

### Download Pre-configured Test File
From the [Download](#download-it) section, we’ll start by grabbing the **Pokemon Autoprint** test file.

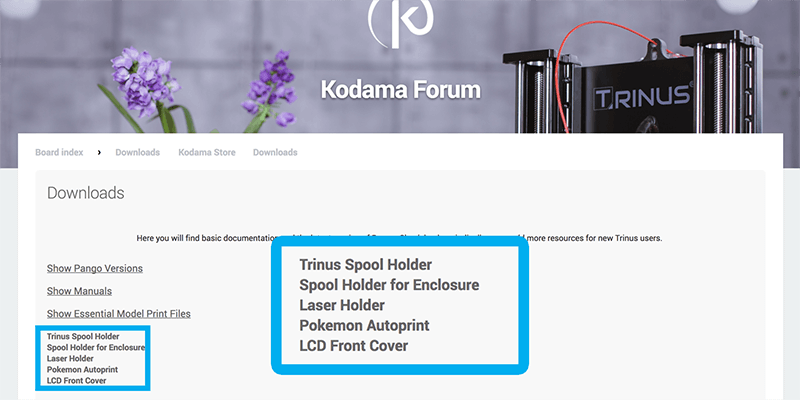
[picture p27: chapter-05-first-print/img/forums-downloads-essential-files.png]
Forums download section


### Start Printing

#### Autoprint File on SD

* Unzip the contents of the file so that you can see the file named "**autoprint.pcode**"
* Copy the **“autoprint.pcode”** file to the root of your SD Card.
* Remove the SD Card from your computer after the file completes writing.
* Now place the SD Card into your printer and push down until it clicks into place. This should cause the Printer to beep twice, telling you it found the "autoprint.pcode" file and it's starting the print.
* After the printing process begins, the extruder needs to heat up to temperature before it starts, you want to pay attention to the first couple layers of filament.
* If the first couple layers aren't sticking to the bed, like the extruder is just dragging them around, you need to eject to the SD card so that the printer stops right away. You want the first layer to have a flat top, but not so flat that you can can see the build plate underneath it (unless you are using transparent filaments, then that’s a different story).
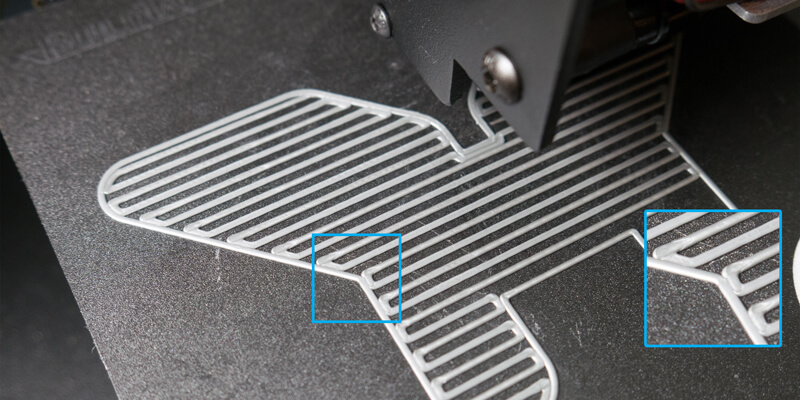
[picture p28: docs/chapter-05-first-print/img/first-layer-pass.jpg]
Good first layer
* Here’s an example of a good first layer 
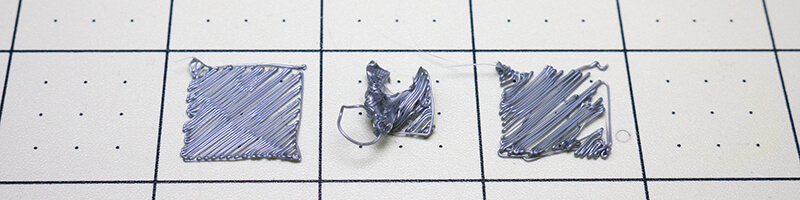
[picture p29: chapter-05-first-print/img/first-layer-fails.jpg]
First layer fails
* Here’s a couple examples of bad first layers. The ones on the left and right had barely enough sticking power to keep it from sticking to the nozzle, but the one in the center wasn’t so lucky. This is why you want to ensure the nozzle is exactly the right distance from the build plate. If you run into these type of issues you may need to go back to the [Set Nozzle Distance](#set-nozzle-distance) section and adjust some more. 

#### Using LCD
If you have the LCD add-on, then you can name the file anything you want when you place it on the SD Card. Simply choose the file from the LCD UI and it will start the printing process.

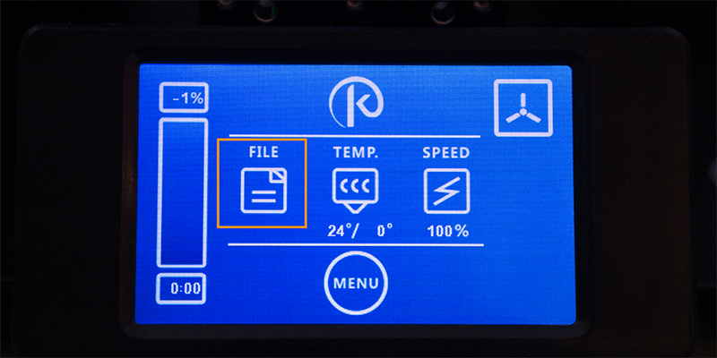
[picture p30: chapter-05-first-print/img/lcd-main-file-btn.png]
LCD - files button
* Click the File icon on the main screen. 
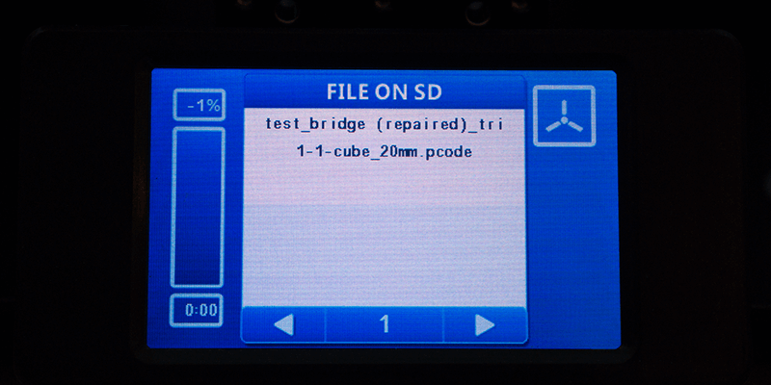
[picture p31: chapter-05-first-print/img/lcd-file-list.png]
LCD - file list
* Choose the file you want to print. 
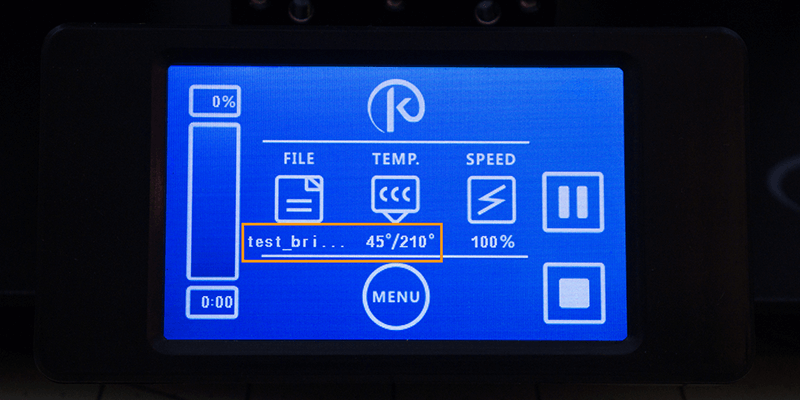
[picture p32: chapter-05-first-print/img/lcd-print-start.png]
LCD - start print
* Then you can see a partial name of the file you selected, the temperature set for the initial layers, as well as Pause and Stop buttons. The bar on the left side of the LCD will show a progress bar (fills up from bottom to top), percentage complete (top), and the current time elapsed (bottom). 

> ##### Tip: No Folders or Special Characters
> Right now the LCD screen won’t let you navigate through folders on the SD Card, so you will need to store all your pcde/gcode files, that you want to print, on the root of the card. Users have also noticed that the file names can only contain AlphaNumeric, Spaces, and Dashes in their names, otherwise it can cause the LCD to just send you back to the main menu without starting the print.

#### Pango Console
If you don’t want to use the “autoprint.pcode” naming convention, for automatic prints, you can simple name the files whatever you want, then print them via the Pango Console.

* Connect to the Pango Console (see [USB Setup](#setup-usb-connection) instructions).
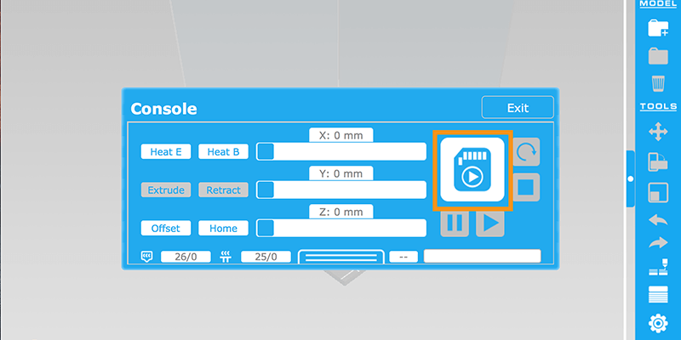
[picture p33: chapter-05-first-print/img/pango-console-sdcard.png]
Pango - console sd card
* Now you can simply click on the SD Card icon. 
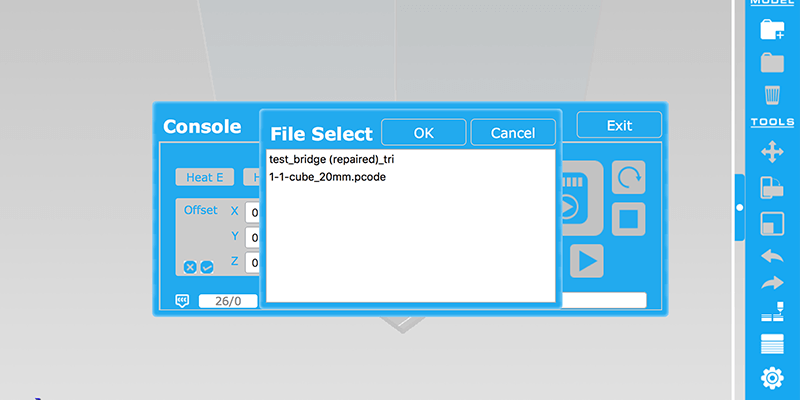
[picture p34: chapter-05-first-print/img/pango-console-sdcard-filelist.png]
Pango - sd card file list
* Choose the file you want to print. 
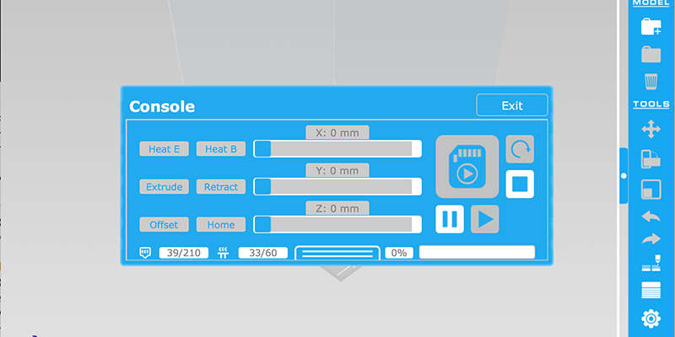
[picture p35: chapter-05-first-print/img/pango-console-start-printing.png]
Pango - console start print
* Then after choosing the file, Pango will automatically close the console and start the printing process (might be a bug, not sure). So if you want to see what’s happening, you will need to re-open the console. At the start of the print you will just notice the Temperature set for the initial layers and the Heated Bed Temperature (bottom left of console). 

### Troubleshooting Print Issues
I would definitely recommend these troubleshooting guides that Simplify 3D and the folks in the Ultimaker Community put together, lots of great information on solving common print issues.

**Simplify 3D Troubleshooting Guide** <br/>
<https://www.simplify3d.com/support/print-quality-troubleshooting/>

**Ultimaker Troubleshooting Guide** <br/>
<http://support.3dverkstan.se/article/23-a-visual-ultimaker-troubleshooting-guide>

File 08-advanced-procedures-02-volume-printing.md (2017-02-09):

### Maximize Build Volume - 3D Printing
Here’s the process to get the maximum use of the build volume, by getting your nozzles “Home” position to be exactly at the front left corner of your build plate.

#### Helpful Print
The following little helper tool will let you easily hand tighten / loosen the offset screw locking nuts. BUT you will first need to use a wrench to loosen them initially, since they were tighten quite a bit during assembly. There are 2 versions of this helper, one of them has a section cut out (right image) that lets you slide the tool over the screw shaft for usage.

**Trinus - Axis Adjustment Helper** <br/> 
[http://www.thingiverse.com/thing:2041158
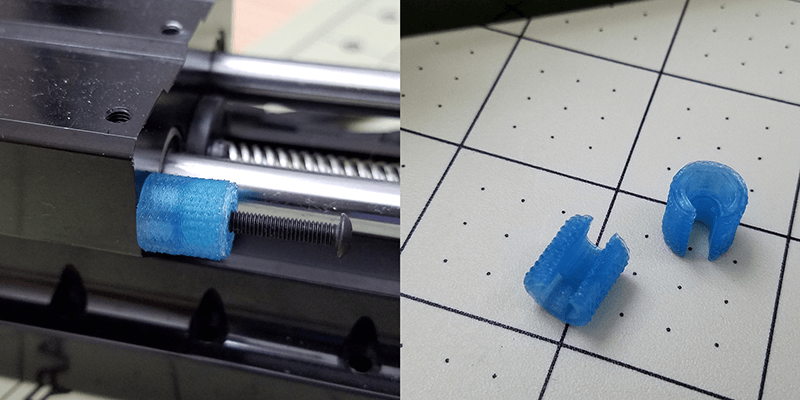
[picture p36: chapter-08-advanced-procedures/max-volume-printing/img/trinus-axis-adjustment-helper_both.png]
Axis adjustment helper tools

](http://www.thingiverse.com/thing:2041158)

#### Adjust the Offset Screws
Now let’s begin the meticulous process of adjusting the offset screws to maximize the build volume.

> ##### WARNING {.warning}
> Just like when you had went through the process to [Set Nozzle Distance](#set-nozzle-distance), you will want to do this with a cold nozzle.

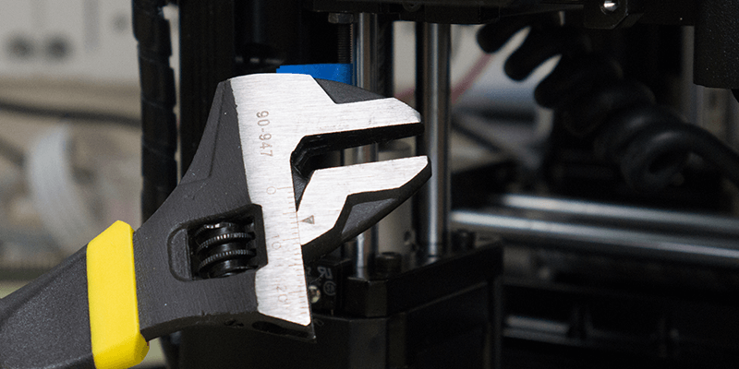
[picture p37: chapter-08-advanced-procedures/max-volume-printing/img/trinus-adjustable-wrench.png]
Use an adjustable wrench
* Loosen all the locking nuts with a wrench, I didn’t have one small enough to fit so I just used an adjustable wrench for this. 
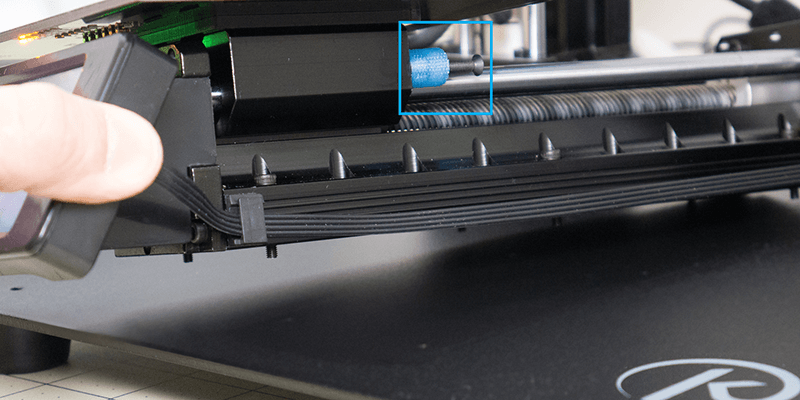
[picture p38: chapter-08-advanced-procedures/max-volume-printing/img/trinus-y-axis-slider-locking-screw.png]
Y-axis slider
* The locking nut on the Y axis (slider holding your bed) is a tough nut to reach. If you don’t want to remove the bed itself, then you can simply unscrew the slider to give you more room to loosen the nut, and install the helper tool. 
* Now that we have things all prepped, it’s time to start tweaking the offset screws. 
* For this part I found that loosening the locking nut (via the helper tool), then adjusting the screws about 2 turns.
 * From the factory you will most likely need to **screw** in the Y axis offset and **unscrew** the X axis.
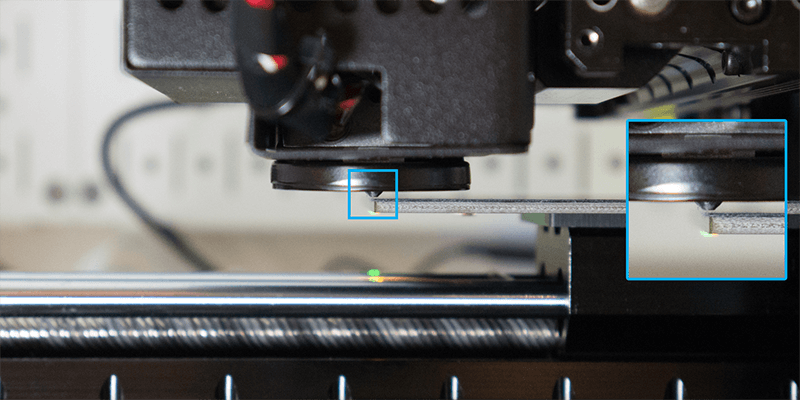
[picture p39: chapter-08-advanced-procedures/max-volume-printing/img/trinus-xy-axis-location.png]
XY axis nozzle location
* Each time you move the screw (in or out)  you will want to Home the axis to check how things look. This is how you want the X / Y distance to look from the corners. 
* Then you need to move the slider to its max position (X = 120, Y = 125) to ensure it’s not going to hit the end of the slider before reaching the max value. This is very important for the Y axis as the nozzle needs to be right at the edge (image above) otherwise it will crash into the front of the slider.
* With your nozzle just above each corner you should now be able to use the entire build volume.

> ##### WARNING {.warning}
> Before trying to move any axis to its max position you need to Home that axis. The Trinus doesn’t know the position of the axis until it’s been homed. So when you change the offset screws, it no longer knows it’s “correct” position, so you need to Home the axis to reset what the “0” position is.

<!-- -->

> ##### Tip: Z-Offset Via 3rd Party Slicer (advanced user)
> If you prefer to use a 3rd Party Slicer for “everything”, then there is a way to set / get the current Z-Offset value via the Terminal window in your prefered slicer. The Terminal window is just a way to send individual Gcode commands to the printer. Here are the 2 commands, first one to get the current value and the second will set the value (positive = closer to bed, negative = further away). These are **case sensitive**, so a lowercase "m" will not work.
> 
> ```
> M628 ; Get Current Z-Offset Value
> M628 Z0.08 ; Set Current Z-Offset Value to 0.08mm
> ```

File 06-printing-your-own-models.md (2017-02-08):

## Printing Your Own Models

### Fixing Your Models
It’s a good practice to make sure the your STL files, which came from your design programs or online repositories, are free of any issues. There is a good chance you can get away with a bad model in your slicer, but that varies depending on the slicer and what sort of auto-fixing features it has build in. This is the sort of thing that is best seen in action, so I found this great video from Angus at [Maker’s Muse](https://www.youtube.com/channel/UCxQbYGpbdrh-b2ND-AfIybg), using a free application called [MeshMixer](http://www.meshmixer.com/):

**Fixing impossible STL's with Meshmixer** <br/>
[https://www.youtube.com/watch?v=8ECNP3WN_-Q
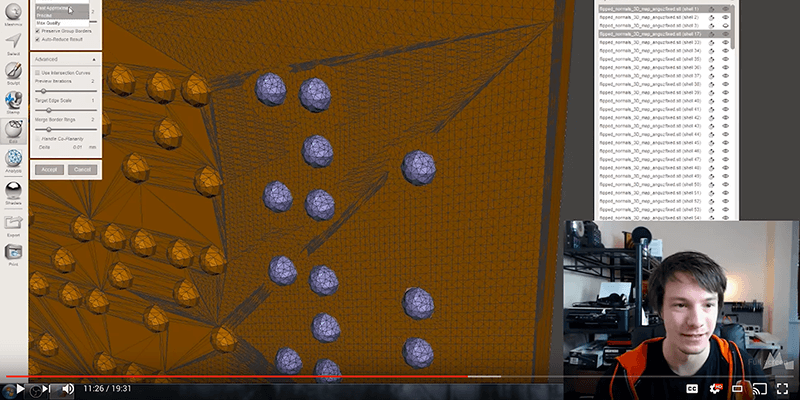
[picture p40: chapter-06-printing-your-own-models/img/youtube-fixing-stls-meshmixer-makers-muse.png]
Makers Muse - Meshmixer tutorial

](https://www.youtube.com/watch?v=8ECNP3WN_-Q)

### Common Pango Settings
Here’s a few basic settings to help you have a successful first print. These options will either be in **Settings** or the **Expert Settings** area. You can find both of these sections listed in the Preferences menu:
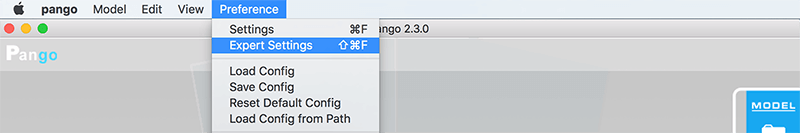
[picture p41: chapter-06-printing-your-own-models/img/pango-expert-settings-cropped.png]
Pango - expert settings


#### Settings
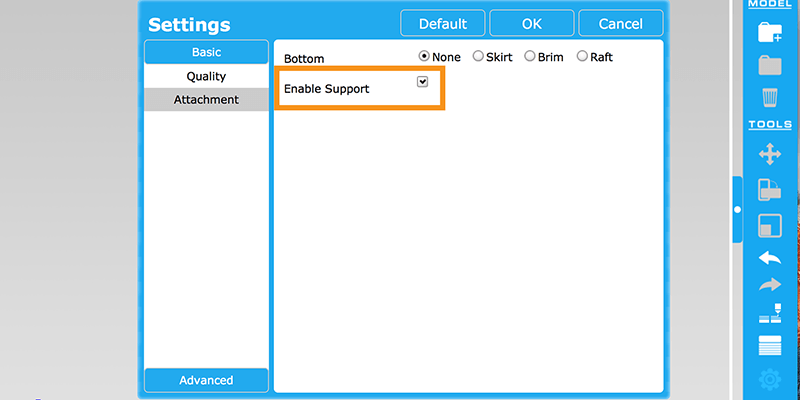
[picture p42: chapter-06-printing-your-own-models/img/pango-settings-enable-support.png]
Pango - enable supports
* **Enable Supports** <br/> If your model has overhangs, nothing supporting it from below, then you may need to Enable Supports when printing. This could leave some blemishes on your final product, but it will also enable you to have a successful print. 
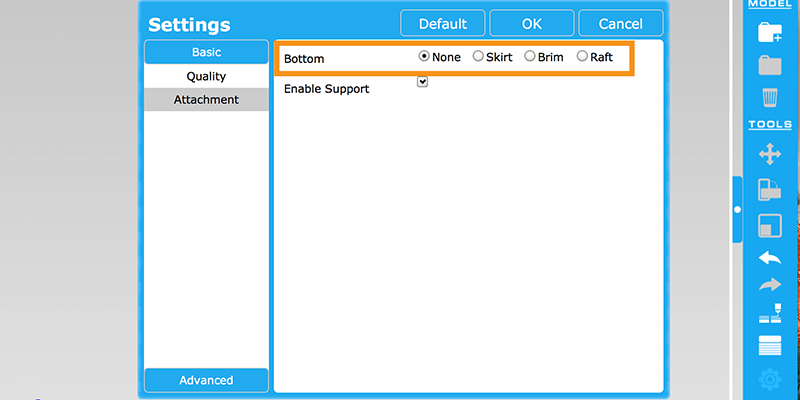
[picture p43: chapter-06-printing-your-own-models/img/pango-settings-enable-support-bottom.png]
Pango - adhesion helpers
* **Adhesion Helpers** 
    * **Rafts** <br/> This can help in 2 ways, if you have a slightly uneven build plate, it will help even things out so that you have a flat surface for your print. It can also help if you need a larger surface area for your print so that it doesn’t fall over / move mid print. You will need to ensure you don’t set to large of a **“Gap Thickness”** (see [Expert Settings](#expert-settings)) as it can reduce this advantage.
    * **Brims** <br/> If you already have a decently flat surface, or your printing on a section of your build plate that's flat enough, you can use a Brim to give you some more holding power. This can also help with preventing warping along the edges of your print, but it will require some clean up after the print is complete.
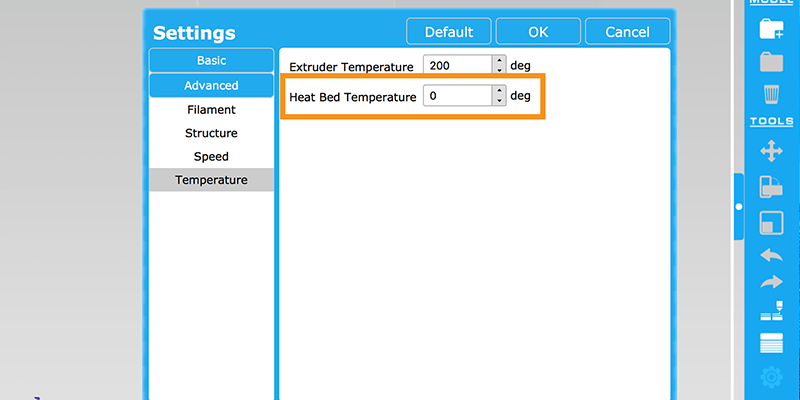
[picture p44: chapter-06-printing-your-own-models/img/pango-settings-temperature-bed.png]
Pango - heated bed temp
* **Heated Bed Temperature** <br/> If you have a heated build plate, you will need to set the temperature for this inside of Pango. Normally you will want to set this value to about 50C-60C for lower temp materials, like PLA, then set it to about 100C for higher temp materials like ABS. 

> ##### WARNING {.warning}
> If this is turned on and you don’t have a heated build plate, the printer will just wait forever until the non-existent build plate heats up (eject sd card to stop).

#### Expert Settings
* **Raft - Gap Thickness** <br/>
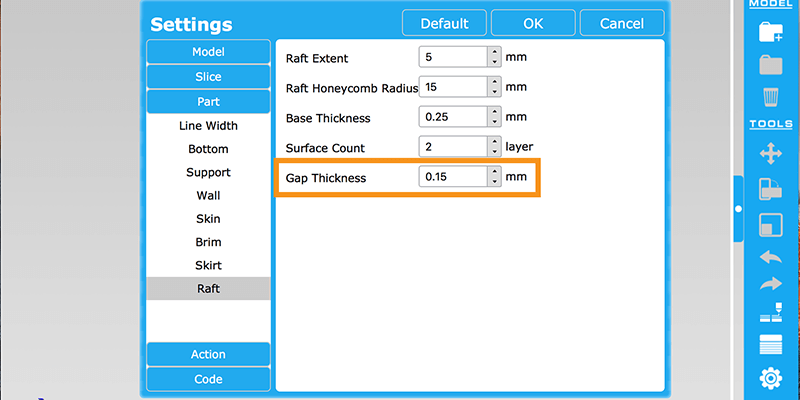
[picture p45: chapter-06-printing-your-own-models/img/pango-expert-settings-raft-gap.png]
Pango - raft expert settings
This is the distance you want your raft to be away from your actual model. Some users have noticed the default setting for this makes the rafts a little hard to remove. So it’s probably a good idea to try a value around **0.2mm**. 

### Start Printing
For the actual printing process, it’s the same thing that has been outlined above in the [First Print](#first-print) section.

> ##### Tip: Free 3D Models
> There are plenty of online repositories with free 3D models you can print. One of the most popular sites is [Thingiverse.com](http://www.thingiverse.com/), but here’s a list of other options to find what you’re looking for: [Best Sites for Free STL Files & 3D Printer Files/Models](https://all3dp.com/best-sites-free-stl-files-3d-printing/) 

<!-- -->

> ##### Tip: Autoprint Name Options
> If you are using Pango to slice your models and currently don’t have the LCD add-on, you’ll need to name your file “**autoprint.pcode**” and store that file at the root of the SD Card. If you plan on using some [other slicer](#third-party-slicers), then you will need to name the file “**autoprint.gcode**”. Since only Pango creates “pcode” files and just about all the other slicers will give you the standard “gcode” file type.

<!-- -->

> ##### Tip: Try, Fail, Learn
> Try new things and fail often, as you’ll learn so much during this process. 3D Printing at home is still in its infancy, so be prepared to fail as you get to know your printer (no matter the make / model). If you can’t figure out how to solve a problem yourself with the guides listed in the [Troubleshooting Print Issues](#troubleshooting-print-issues), then please post in the official [Facebook Group](https://www.facebook.com/groups/Trinus3D/) and/or [Forums](http://www.kodamaforums.com/).

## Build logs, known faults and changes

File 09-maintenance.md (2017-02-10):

## Maintenance

This is where you can find out how to make your printer last a long time and ensure it’s running smoothly.

### Axis Sliders
Here’s a video from Marius Hirn on how to take apart the Axis sliders, clean, grease, and put it all back together again. This will also be helpful if you need to remove backlash (back and forth) movement on the sliders (by tightening the spring a bit more).

**TRINUS 3d printer slider disassembling and greasing** <br/>
[https://www.youtube.com/watch?v=7NlR7_E2QIo
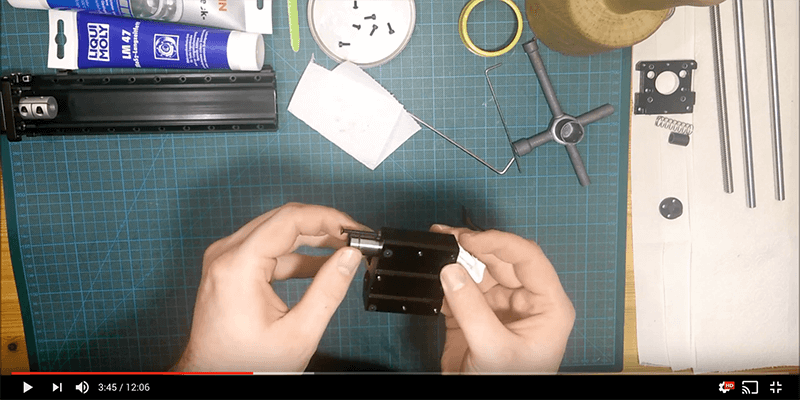
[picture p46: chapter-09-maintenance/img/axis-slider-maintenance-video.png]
Slider disassembling and greasing

](https://www.youtube.com/watch?v=7NlR7_E2QIo)

**Grease Recommendations** <br/>
Liqui Moly Mos2 Long-life Grease - [US](http://amzn.to/2l9xzyq) / [UK](https://www.amazon.co.uk/dp/B00295CR0U/) <br/>
Super Lube - [US](http://amzn.to/2jP4wzi) / [UK](https://www.amazon.co.uk/d/B000XBH9HI)

### Nozzle Cleaning - Cold Pulling
Here’s a method known as Cold Pulling, where you heat up the nozzle just enough to get the filament soft, then reduce the temp so it’s a bit more firm, and pull it out. You can repeat this process until the nozzle is clean.

* Heat nozzle to 160C
* Push down the lever and manually push the filament into the nozzle so that some extruders.
* Now reduce the temperature to 90C.
* Push down the lever again and pull the filament out. This can require a bit of force to pull out, but the filament should be soft enough that you can pull it out without hurting anything.
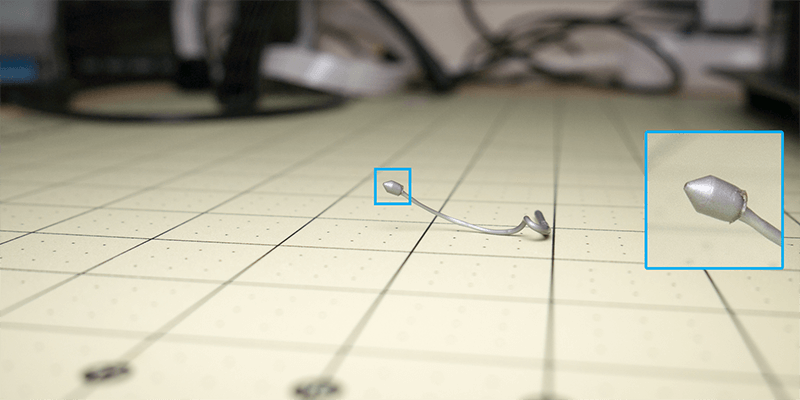
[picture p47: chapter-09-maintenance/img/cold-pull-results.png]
Good cold pull
* If there was something stuck on your hotend, it should be attached to the filament you pulled out. Just keep repeating this “heat, cool, pull” process until the nozzle comes out clean like the following image. 

#### Still have more questions?

**Thomas Sanladerer - Basics: Cleaning out a clogged nozzle** <br/>
[https://www.youtube.com/watch?v=g8uvh6kvr54
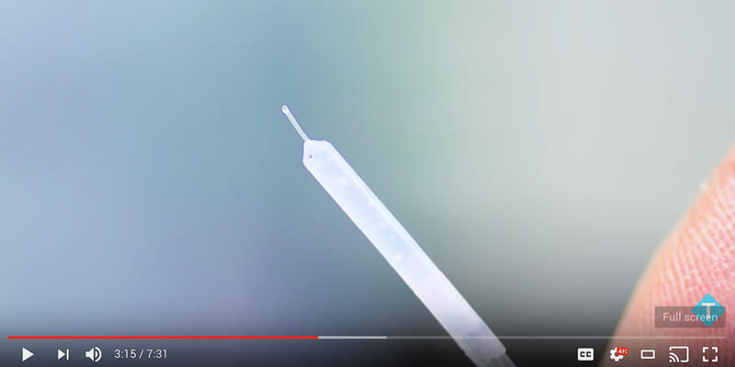
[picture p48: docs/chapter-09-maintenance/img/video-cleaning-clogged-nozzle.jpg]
Thomas Sanladerer - Basics: Cleaning out a clogged nozzle

](https://www.youtube.com/watch?v=g8uvh6kvr54)

> ##### Tip: Using Nylon
> Some people love to use Nylon filament for this process as it does a great job of holding on to the gunk that might be stuck in the nozzle. If you plan on doing this, you will want to heat the nozzle to 230C, then reduce to 100C for the pull.

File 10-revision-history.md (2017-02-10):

## Revision History

Find all the changes that have been made since you last downloaded a copy of this guide. All dates are listed in Year / Month / Day format.

**2017 / 02 / 10**

* Added a video from Thomas Sanladerer about the basics of cleaning out a clogged nozzle. ([link](#nozzle-cleaning---cold-pulling))
* Changed the image showing a good first layer print, since the other one was a little out of focus. ([link](#start-printing))

**2017 / 02 / 09**

* Converted the beginners guide to Markdown format so that the original source can be shared via Github.com, this also allows for community contributions. ([link](https://github.com/drofnas/trinus-unofficial-beginners-guide))
* Maintenance Section added, starting with a video breaking down & greasing the sliders, plus how to clean your nozzle via a cold pull. ([link](#maintenance))
* Added a warning message about over-tightening screws for the tool attachment. ([link](#getting-started-videos))

**2017 / 02 / 04**

* Added a Revision History.
* Tip on how to set the software Z-Offset via 3rd Party Slicers, shown at the end of the Maximize Build Volume section. ([link](#maximize-build-volume---3d-printing))
* Note about lack of USB printing support in Cura. ([link](#cura))
* How to update your firmware added to the Advanced Procedures section. Also added a link to this section in the Pre-Check for Laser Engraving. ([link](#pre-check-1))
* Information on the missing spool holder. ([link](#spool-holder))

**2017 / 01 / 31**

* This was the very first version released publicly.

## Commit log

2017-02-07 Initial conversion of the Google Doc to Markdown. Images currently not included, coming soon.
2017-02-08 Updated the html/css and the pdf created from them. Since I had used someone elses Markdown css I didn't realize they had a media=print section which was causing the output of my PDFs to be black and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
2017-02-08 Nozzle Distance - internal links added, also went back and added some bold sections to the previous sections.
2017-02-08 First Print - links added and some extra font styling.
2017-02-08 Printing own models - links added and some font styling.
2017-02-08 Laser engraving - links and styles added.
2017-02-09 Just a couple updates to the main README file.
2017-02-09 Added in the Offset Laser Holder STL file since it was referenced in the document, might as well store it in this github.
    [trinus-offset_laser_holder.stl]
2017-02-09 Added a reference to the offset laser point thats stored in github and minor tweaks to the README.
2017-02-09 Updated the Revision History for the current release and generated the HTML/PDF documents.
2017-02-09 Added some minor styling tweaks and also added page breaks at the start of every new sectionn, so that the PDF looks a little cleaner when using the Save as PDF option in the Chrome Print Dialog.
2017-02-09 Moving things around to make better use of the Github Pages
    [trinus-offset_laser_holder.stl]
2017-02-10 Updated the image for a good first layer and added a cleaning nozzle video link from Thomas Sanladerer.
